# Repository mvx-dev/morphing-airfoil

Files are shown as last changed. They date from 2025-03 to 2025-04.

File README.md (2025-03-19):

# DESN1K Morphing Wing Main Repository
---
The main repository for uploading project files for the morphing wing project.

## Directories
---
Airfoils: any files relating to airfoil design. This include txt files, STL files, and Solidworks part files

Minutes: the minutes for every meeting

Embedded Systems: all files relating to embedded system design. This includes schematics, PCB files, etc

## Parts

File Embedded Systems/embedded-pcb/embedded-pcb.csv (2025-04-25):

Reference | Qty | Value | Footprint
A1 | 1 | Arduino_Nano_v2.x | Module:Arduino_Nano
C1,C2 | 2 | 220nF | Capacitor_THT:C_Disc_D3.8mm_W2.6mm_P2.50mm
C3,C4 | 2 | 10uF | Capacitor_THT:CP_Radial_D5.0mm_P2.50mm
D1,D2 | 2 | LED | LED_THT:LED_D5.0mm
J1 | 1 | Servos | Connector_PinSocket_2.54mm:PinSocket_1x06_P2.54mm_Vertical
J2 | 1 | Screw_Terminal_01x02 | TerminalBlock:TerminalBlock_bornier-2_P5.08mm
R1,R2,R3,R4 | 4 | 220 | Resistor_THT:R_Axial_DIN0207_L6.3mm_D2.5mm_P10.16mm_Horizontal
R5,R6,R7,R8 | 4 | 1k | Resistor_THT:R_Axial_DIN0207_L6.3mm_D2.5mm_P10.16mm_Horizontal
R9,R10 | 2 | 47 | Resistor_THT:R_Axial_DIN0207_L6.3mm_D2.5mm_P10.16mm_Horizontal
Rsen1,Rsen2 | 2 | 10k | Resistor_THT:R_Axial_DIN0207_L6.3mm_D2.5mm_P10.16mm_Horizontal
RV1,RV2 | 2 | 1k | Connector_Wire:SolderWire-0.1sqmm_1x03_P3.6mm_D0.4mm_OD1mm
SW1,SW2,SW3 | 3 | SW_SPDT | Connector_Wire:SolderWire-0.1sqmm_1x03_P3.6mm_D0.4mm_OD1mm
U1 | 1 | LM324 | Package_DIP:DIP-14_W7.62mm
U2 | 1 | LM7805_TO220 | Package_TO_SOT_THT:TO-220-3_Vertical
U3 | 1 | LM1117T-3.3 | Package_TO_SOT_THT:TO-220-3_Vertical

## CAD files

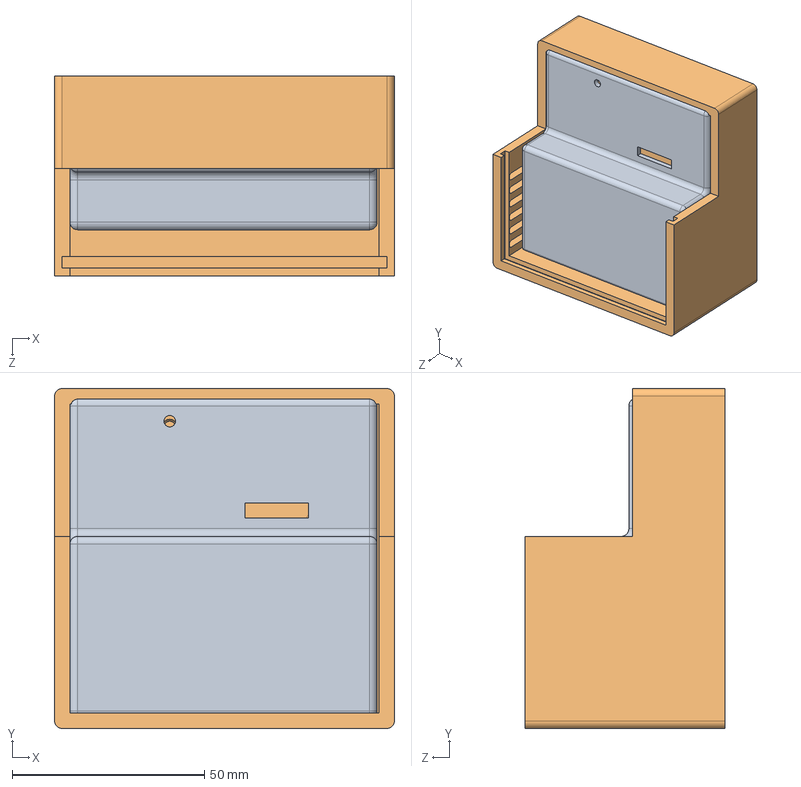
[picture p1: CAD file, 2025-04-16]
Embedded Systems/Housing/housing.SLDASM
88.5 x 88.5 x 52.0 mm
bottom-housing
cover

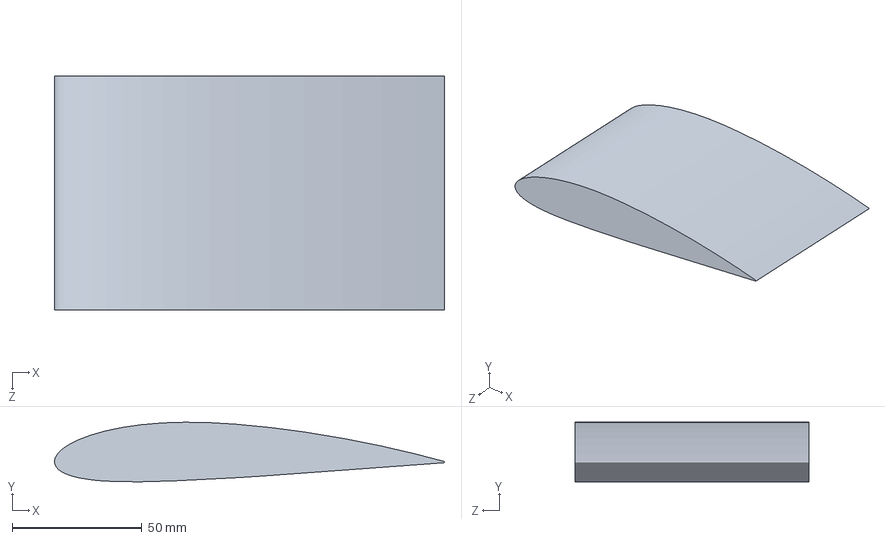
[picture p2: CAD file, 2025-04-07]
Airfoils/3415 airfoil base.SLDPRT
150.1 x 23.0 x 90.0 mm

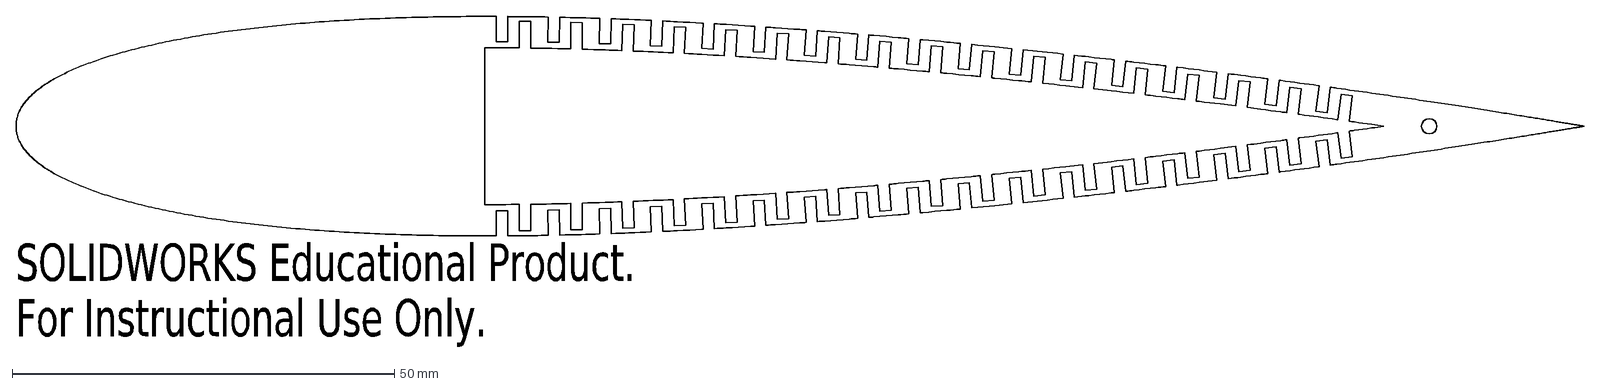
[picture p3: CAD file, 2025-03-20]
Mechanisms/Adam/0014v2.DXF
SOLIDWORKS Educational Product.
For Instructional Use Only.

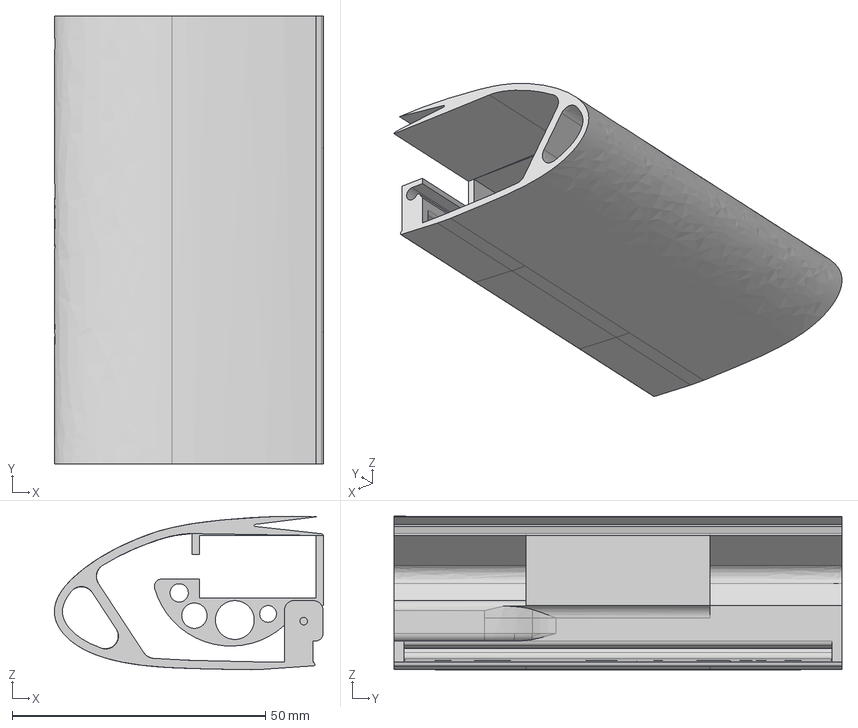
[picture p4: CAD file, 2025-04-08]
Mechanisms/CG V7 core.step
53.1 x 88.4 x 30.3 mm

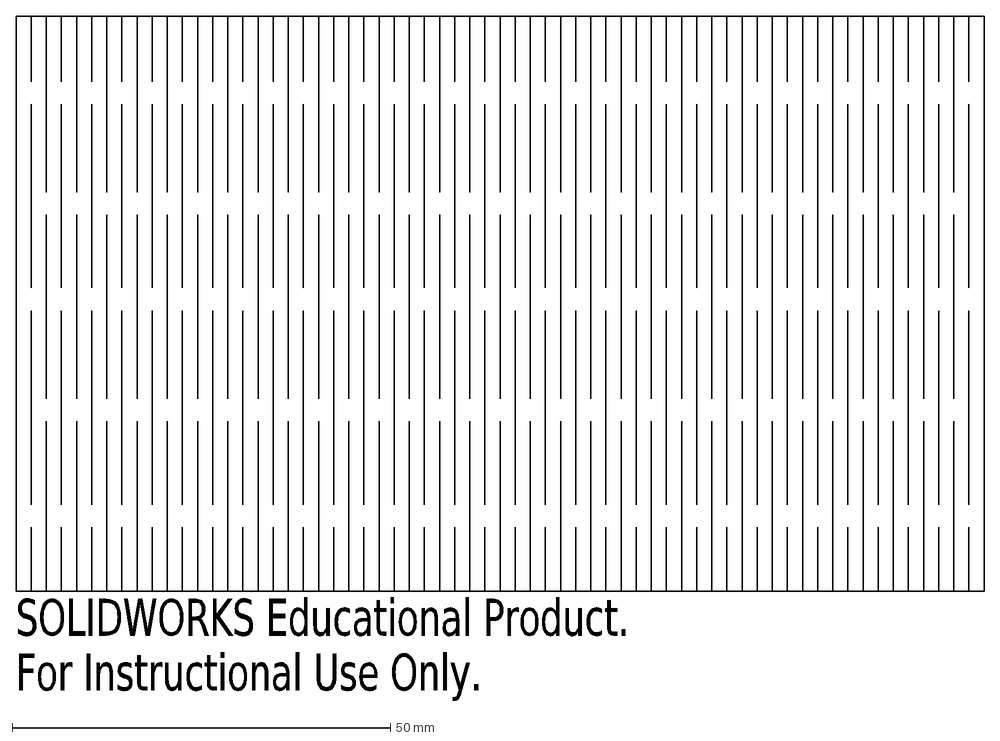
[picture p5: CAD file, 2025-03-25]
Mechanisms/Oskar/flexible-skin2.DXF
SOLIDWORKS Educational Product.
For Instructional Use Only.

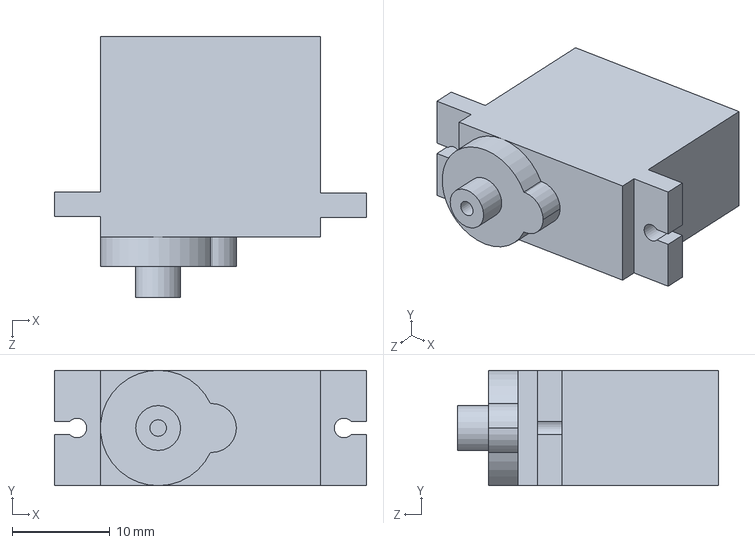
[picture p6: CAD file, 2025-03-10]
sg90.SLDPRT
31.9 x 11.8 x 26.7 mm

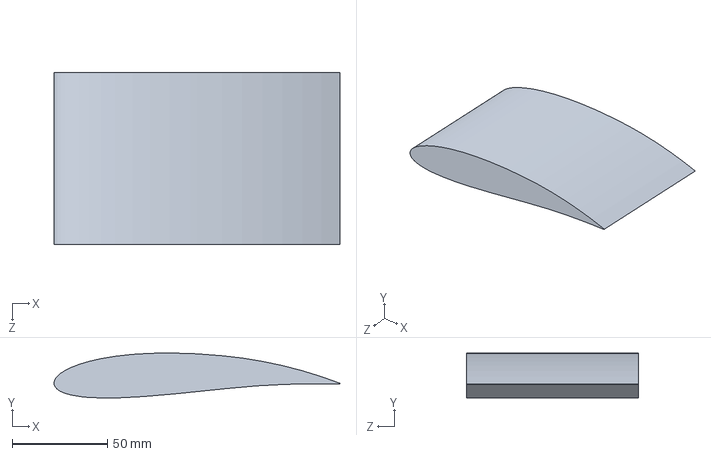
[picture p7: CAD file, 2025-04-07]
Airfoils/4615 airfoil base.SLDPRT
150.1 x 23.6 x 90.0 mm

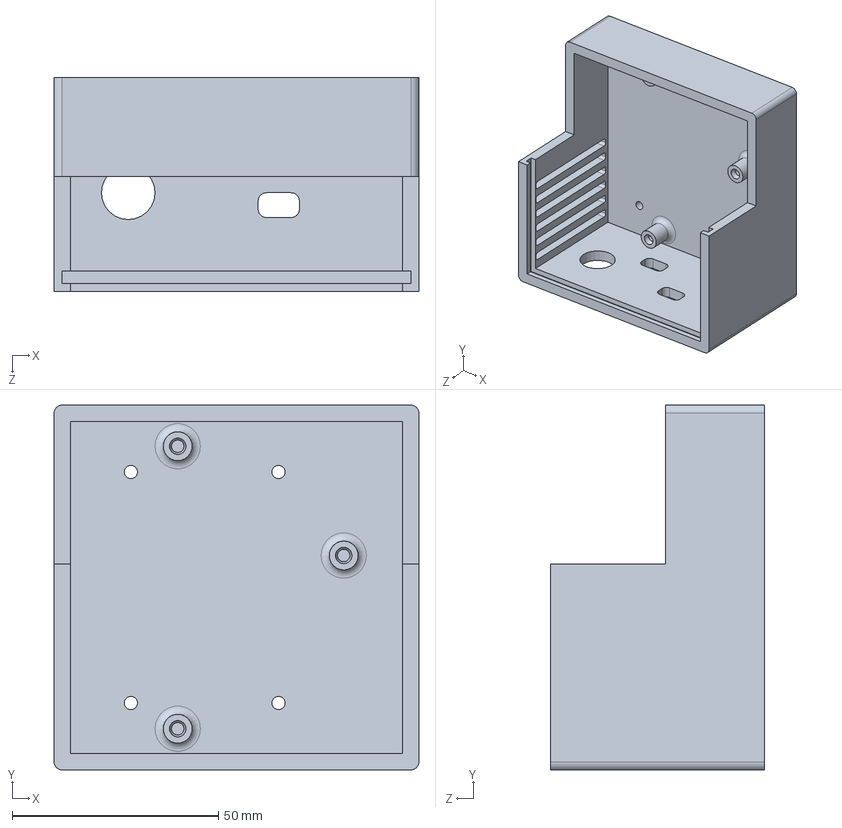
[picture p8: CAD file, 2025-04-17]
Embedded Systems/Housing/bottom-housing.SLDPRT
88.5 x 88.5 x 52.0 mm

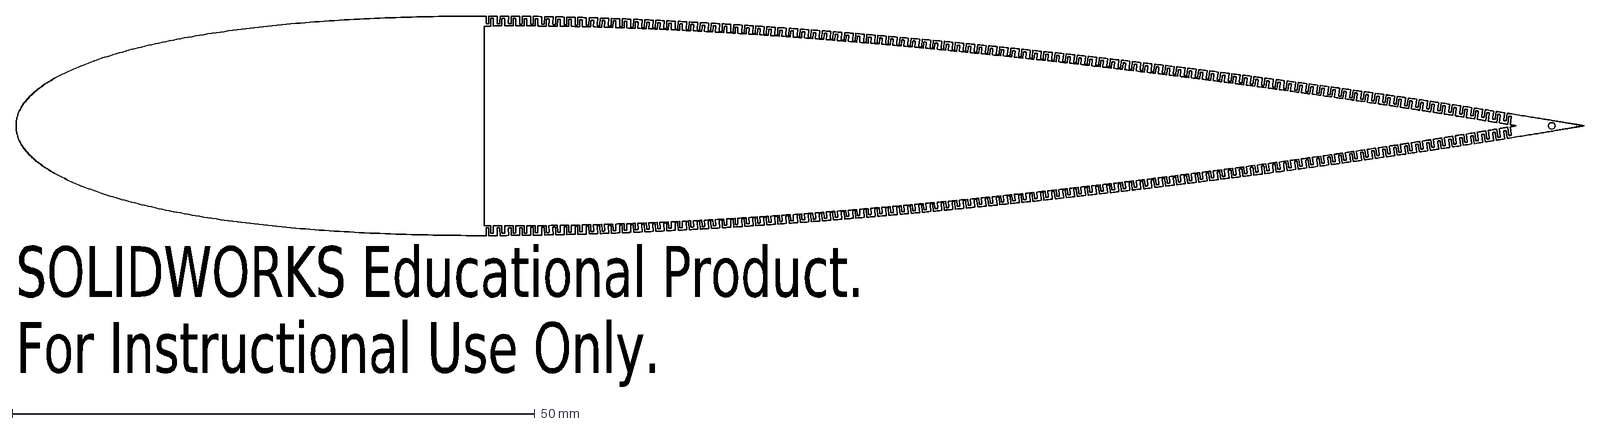
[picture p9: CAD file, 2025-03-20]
Mechanisms/Adam/0014v1.DXF
SOLIDWORKS Educational Product.
For Instructional Use Only.

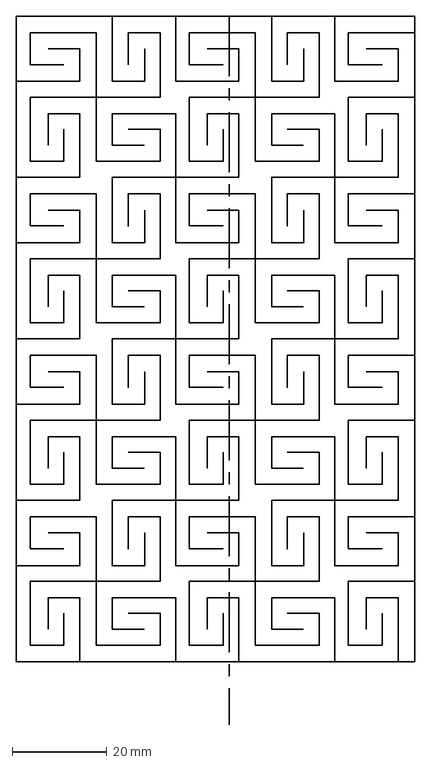
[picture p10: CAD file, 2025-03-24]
Mechanisms/Oskar/flexible-skin1.DXF
84.2 x 150.0 mm

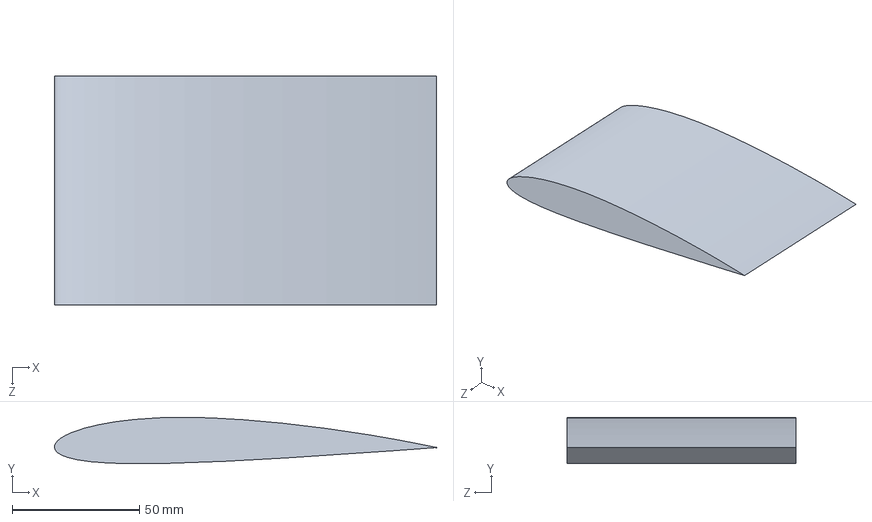
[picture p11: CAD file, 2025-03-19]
Airfoils/2412.SLDPRT
150.0 x 18.2 x 90.0 mm

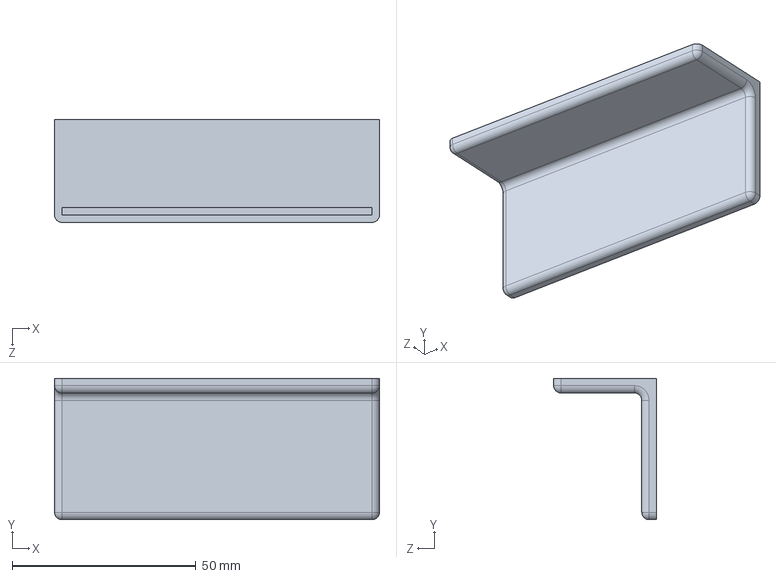
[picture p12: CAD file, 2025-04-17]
Embedded Systems/Housing/latch.SLDPRT
88.5 x 38.5 x 28.0 mm

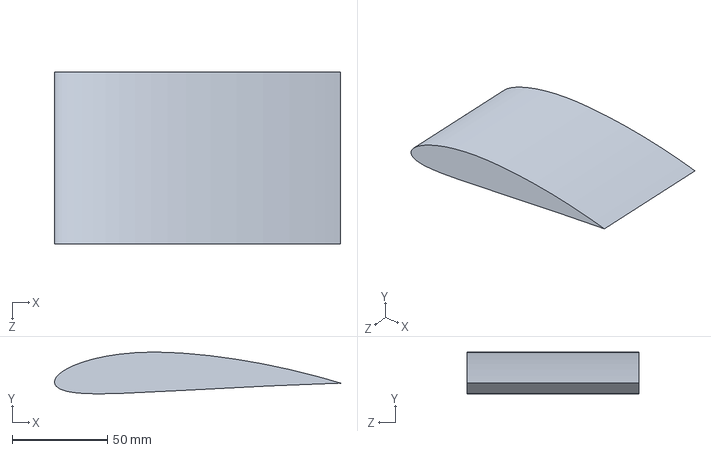
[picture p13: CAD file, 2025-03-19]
Airfoils/4414.SLDPRT
150.1 x 21.9 x 90.0 mm

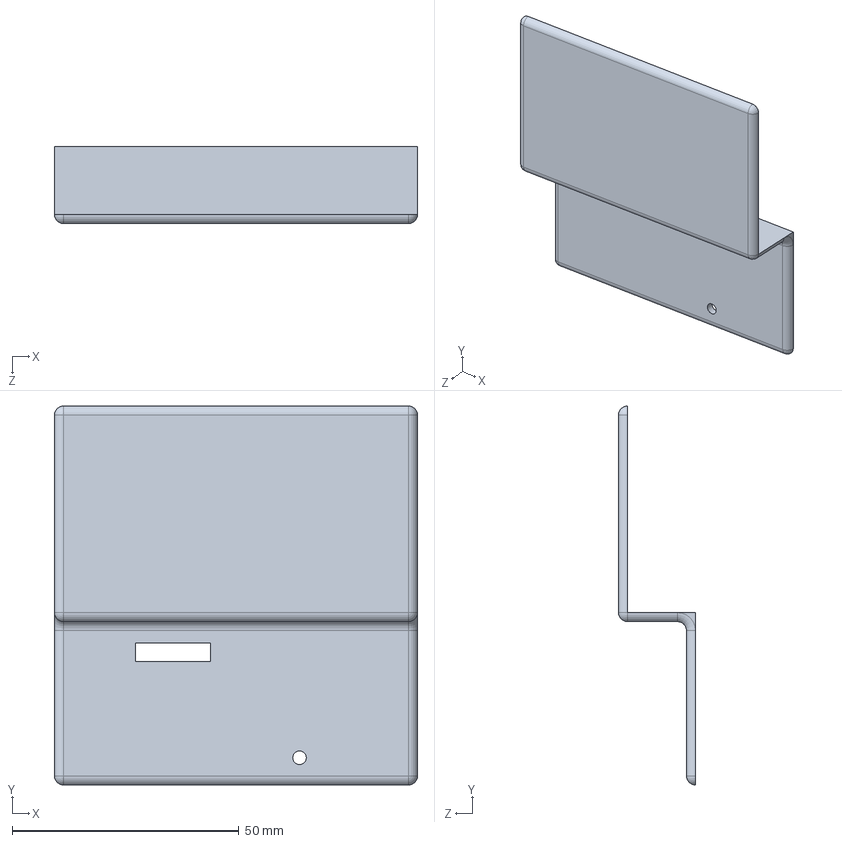
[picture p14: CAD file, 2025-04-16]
Embedded Systems/Housing/cover.SLDPRT
80.0 x 83.5 x 17.0 mm

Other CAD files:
Embedded Systems/Housing/lid.SLDPRT
Airfoils/2414.SLDPRT
Embedded Systems/Housing/baseplate.SLDPRT
Airfoils/2412.STL
Airfoils/2414.STL
Airfoils/4414.STL
Embedded Systems/Housing/lid.DXF

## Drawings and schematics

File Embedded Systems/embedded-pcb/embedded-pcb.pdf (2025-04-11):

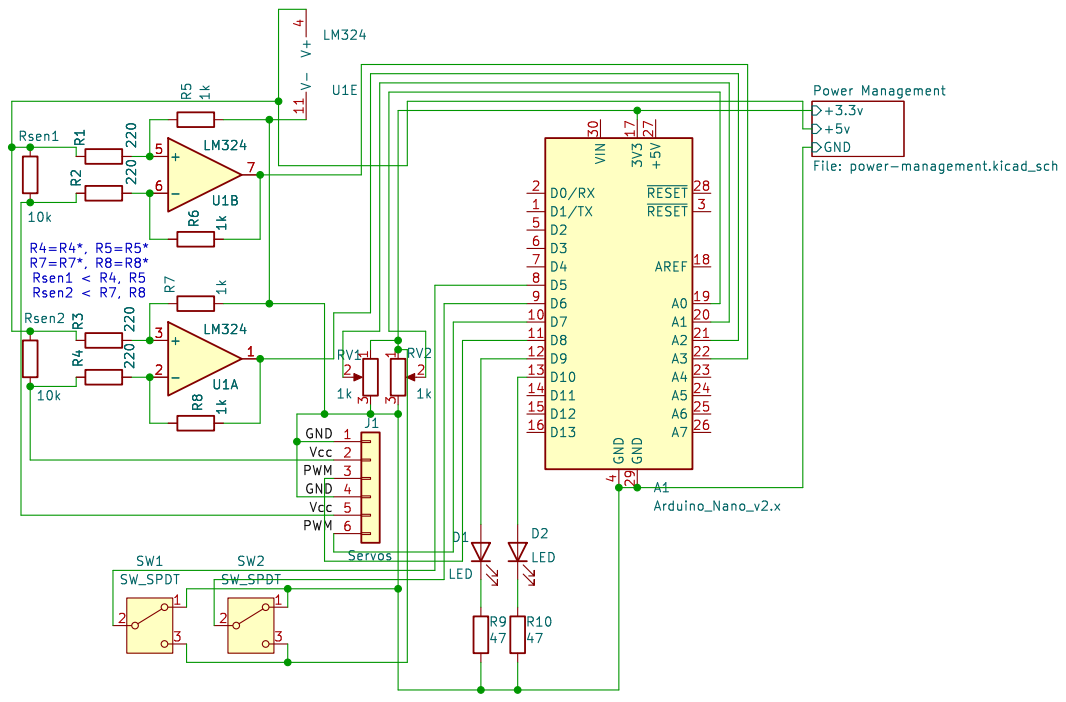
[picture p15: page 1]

Power Management File: power-management.kicad_sch D1

File: embedded-pcb.kicad_sch Sheet: / Email: o.meszaros@student.unsw.edu.au

Id: 1/2 Title: Morphing wing PCB

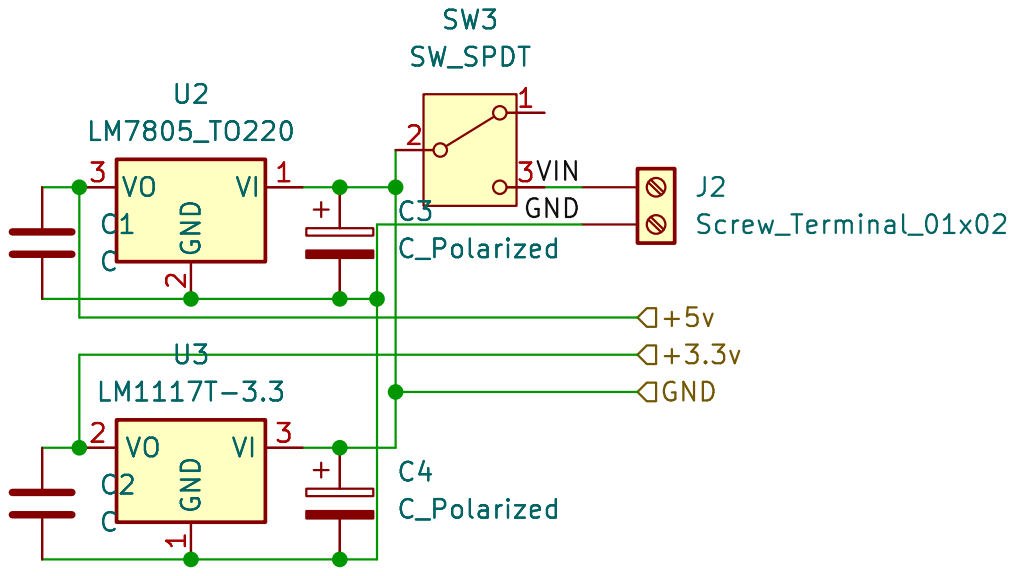
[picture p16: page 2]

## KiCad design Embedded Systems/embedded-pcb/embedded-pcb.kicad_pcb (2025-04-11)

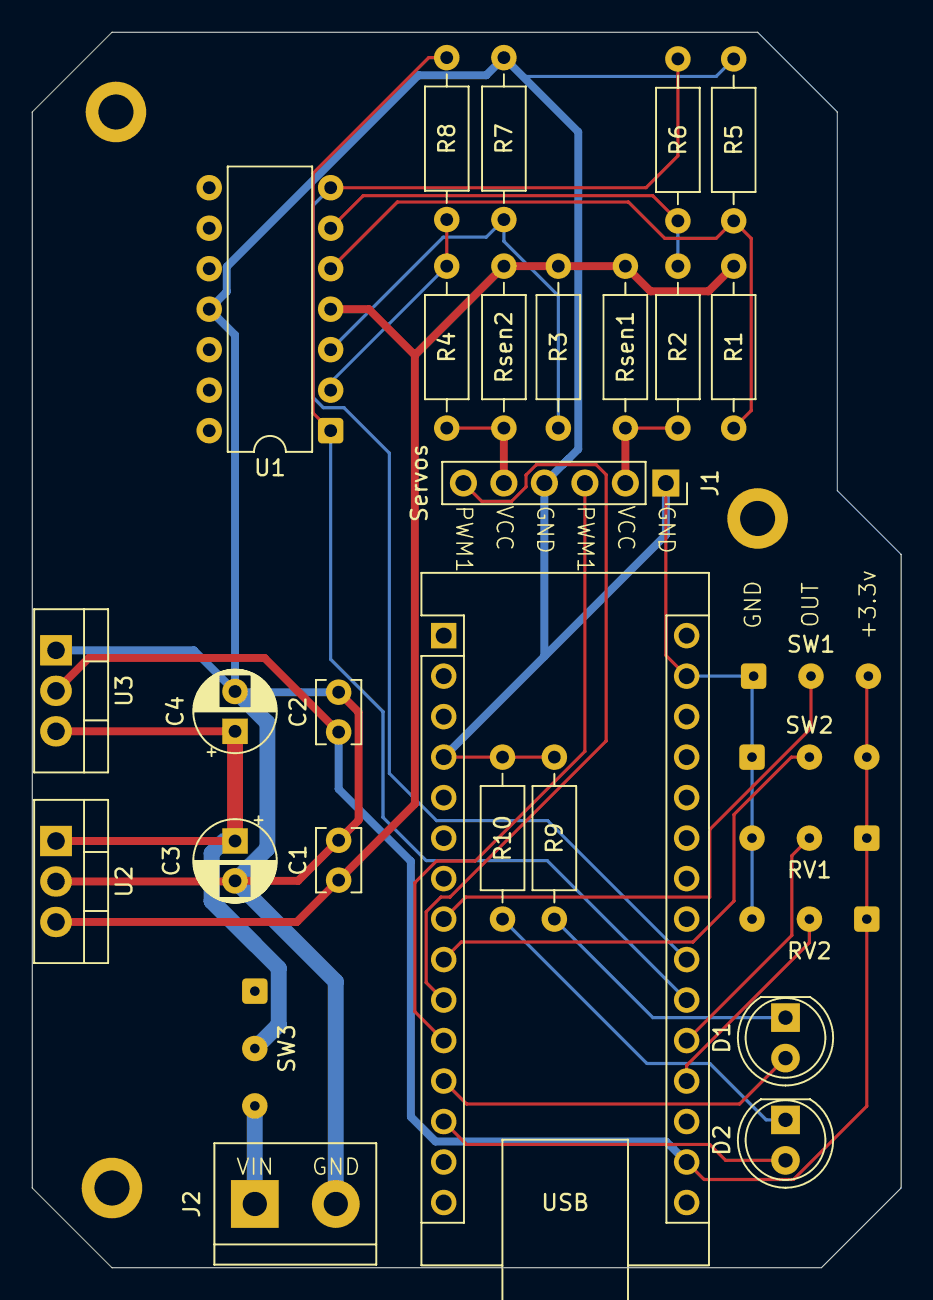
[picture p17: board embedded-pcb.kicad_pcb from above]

Board: 2 copper layers, 54.5 x 77.5 mm, 29 parts (0 on the bottom side), 20 nets.

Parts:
A1: Arduino_Nano_v2.x; Arduino_Nano
C1, C2: C; C_Disc_D3.8mm_W2.6mm_P2.50mm
C3, C4: C_Polarized; CP_Radial_D5.0mm_P2.50mm
D1, D2: LED; LED_D5.0mm
J1: Servos; PinSocket_1x06_P2.54mm_Vertical
J2: Screw_Terminal_01x02; TerminalBlock_bornier-2_P5.08mm
R1, R2, R3, R4: 220; R_Axial_DIN0207_L6.3mm_D2.5mm_P10.16mm_Horizontal
R5, R6, R7, R8: 1k; R_Axial_DIN0207_L6.3mm_D2.5mm_P10.16mm_Horizontal
R9, R10: 47; R_Axial_DIN0207_L6.3mm_D2.5mm_P10.16mm_Horizontal
RV1, RV2: 1k; SolderWire-0.1sqmm_1x03_P3.6mm_D0.4mm_OD1mm
Rsen1, Rsen2: 10k; R_Axial_DIN0207_L6.3mm_D2.5mm_P10.16mm_Horizontal
SW1, SW2, SW3: SW_SPDT; SolderWire-0.1sqmm_1x03_P3.6mm_D0.4mm_OD1mm
U1: LM324; DIP-14_W7.62mm
U2: LM7805_TO220; TO-220-3_Vertical
U3: LM1117T-3.3; TO-220-3_Vertical

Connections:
/GND: A1.4 (GND), A1.29 (GND), C1.2, C2.2, C3.1, C3.2, C4.1, C4.2, J1.1, J1.4, J2.2, R5.2, R7.2, R9.2, R10.2, RV1.3, RV2.3, SW1.1 (A), SW2.1 (A), SW3.2 (B), U1.11 (V-), U2.1 (VI), U2.2 (GND), U3.1 (GND), U3.3 (VI)
/PWM: A1.10 (D7), A1.11 (D8), J1.3, J1.6
/Power Management/+3.3v: A1.17 (3V3), C2.1, RV1.1, RV2.1, SW1.3 (C), SW2.3 (C), U3.2 (VO)
/Power Management/+5v: C1.1, R1.1, R3.1, Rsen1.1, Rsen2.1, U1.4 (V+), U2.3 (VO)
/Power Management/VIN: J2.1, SW3.3 (C)
/Vcc: J1.2, J1.5, R2.1, R4.1, Rsen1.2, Rsen2.2
unnamed: A1.19 (A0), RV2.2
unnamed: A1.20 (A1), RV1.2
unnamed: A1.21 (A2), R8.2, U1.1
unnamed: A1.22 (A3), R6.2, U1.7
unnamed: A1.8 (D5), SW1.2 (B)
unnamed: A1.9 (D6), SW2.2 (B)
unnamed: A1.12 (D9), D1.2 (A)
unnamed: A1.13 (D10), D2.2 (A)
unnamed: D1.1 (K), R9.1
unnamed: D2.1 (K), R10.1
unnamed: R3.2, R7.1, U1.3 (+)
unnamed: R4.2, R8.1, U1.2 (-)
unnamed: R1.2, R5.1, U1.5 (+)
unnamed: R2.2, R6.1, U1.6 (-)

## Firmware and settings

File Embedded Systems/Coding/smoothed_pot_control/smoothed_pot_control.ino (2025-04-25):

/*
  smoothed_pot_control v1.0

  Controls two servos by reading the voltage across two potentiometers, and
  optionally smooth the outputs by calculating a sliding average.

  created 03 Apr 2025
  by Oskar Meszaros
  zID z5636164
  email o.meszaros@student.unsw.edu.au
*/
#include <Servo.h>

/* Define I/O pins */
const int POT1 = A0;
const int POT2 = A1;
const int LEDPIN1 = 2; // LED1 in use
const int LEDPIN2 = 3; // LED2 in use
const int SWITCH2 = 4;
const int SWITCH1 = 5;
const int SERVO1 = 9;
const int SERVO2 = 7;

/* Define servos*/
Servo servo1;
Servo servo2;

/* Define program variables*/
int servo1_pos = 0;
int servo2_pos = 0;
int pot1_value = 0;
int pot2_value = 0;
int pot1_old = 0;
int pot2_old = 0;
int switch1_value = LOW; // LOW = Smoothing off, HIGH = Smoothing on
int switch2_value = LOW;

int threshold = 4;
bool moving = false;

const int smoothingSteps = 48;
int pot1_readings[smoothingSteps] = {0};
int pot2_readings[smoothingSteps] = {0};

int pot_to_servo(int value) {
  /* Translate potentiometer value to servo position */
  return (value/1023.0) * 180;
}

int smooth_value(int value, int readings[]) {
  /* Update the reading buffer and return average */
  int total = 0;
  
  for (int i = 0; i < smoothingSteps-1; i++) {
    readings[i] = readings[i+1];
    total += readings[i];
  }

  readings[smoothingSteps-1] = value;
  total += value;
  
  return (int)(total/smoothingSteps);
}

void calibrate(int cycles, int gap, int pot_pin, int readings[]) {
  /*
  Propogates the buffer with values to prevent the servo moving prior to having the correction position.
  Fills buffer cycles times.
  */
  for (int cycle = 0; cycle < cycles; cycle++){
    for (int i = 0; i < smoothingSteps; i++) {
      int pot_value = analogRead(pot_pin);
      smooth_value(pot_value, readings);
      delay(gap);
    }
  }
}

void setup() {
  /* Configure pins*/
  pinMode(LEDPIN1, OUTPUT);
  pinMode(LEDPIN2, OUTPUT);
  pinMode(SWITCH1, INPUT);
  pinMode(SWITCH2, INPUT);

  /* Attach Servos */
  servo1.attach(SERVO1);
  servo2.attach(SERVO2);

  /* Calibrate potentiometer smoothing */
  digitalWrite(LEDPIN1, HIGH);
  calibrate(8, 10, POT1, pot1_readings);
  calibrate(8, 10, POT2, pot2_readings);
  digitalWrite(LEDPIN1, LOW);
  delay(100);
  digitalWrite(LEDPIN1, HIGH);
  delay(100);
  digitalWrite(LEDPIN1, LOW);

  /* Begin Serial */
  Serial.begin(9600);
}

void loop() {
  /* Read all inputs */
  pot1_old = pot1_value;
  pot2_old = pot2_value;
  pot1_value = analogRead(POT1);
  pot2_value = analogRead(POT2);

  switch1_value = digitalRead(SWITCH1);
  switch2_value = digitalRead(SWITCH2);

  /* Smooth potentiometer input. Still add to buffer if not. */
  if (switch1_value == HIGH) {
    pot1_value = smooth_value(pot1_value, pot1_readings);
  } else {
    smooth_value(pot1_value, pot1_readings);
  }

  if (switch2_value == HIGH) {
    pot2_value = smooth_value(pot2_value, pot2_readings);
  } else {
    smooth_value(pot2_value, pot2_readings);
  }

  /* Indicator light*/
  int delta1 = pot1_old - pot1_value;
  int delta2 = pot2_old - pot2_value;

  if ((delta1 < -threshold) or (delta1 > threshold)) {
    moving = true;
  }
  if ((delta2 < -threshold) or (delta2 > threshold)) {
    moving = true;
  }

  if (moving) {
    moving = false;
    digitalWrite(LEDPIN1, HIGH);
    digitalWrite(LEDPIN2, LOW);
  } else {
    digitalWrite(LEDPIN1, LOW);
    digitalWrite(LEDPIN2, HIGH);
  }

  /* Update servos */
  servo1_pos = pot_to_servo(pot1_value);
  servo2_pos = pot_to_servo(pot2_value);

  servo1.write(servo1_pos);
  servo2.write(servo2_pos);

  delay(10);
}

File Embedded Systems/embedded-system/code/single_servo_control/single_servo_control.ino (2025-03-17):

#include <Servo.h>


Servo servo;  // create servo object to control a servo

// Define pins
const int POT_IN = A0;
// const int SERVO_IN = A1;
const int SERVO_OUT = 10;

// Program variables
int servo_pos = 0;
int pot_value = 0;
int servo_value = 0;

float potToServo(int pot) {
  float ratio = pot / 1023.0;
  return ratio * 180.0;
}

void setup() {
  servo.attach(SERVO_OUT);  // attaches the servo on pin 9 to the servo object
  servo.write(0);  // Home it to 0
  delay(50);

  // Configure serial
  Serial.begin(9600);
}

void loop() {
  pot_value = analogRead(POT_IN);
  servo_pos = potToServo(pot_value);
  // servo_value = analogRead(SERVO_IN);
  Serial.print(pot_value);
  Serial.print("\t");
  // Serial.print(servo_value);
  // Serial.print("\t");
  Serial.println(servo_pos);

  servo.write(servo_pos);

  delay(10);
}

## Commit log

2025-03-10 feat: SG90 solidworks part
    3D model of the SG90 servo motor for use in the morphing wing
    [sg90.SLDPRT]
2025-03-14 feat: embedded system project files
    [embedded-system.kicad_pcb, embedded-system.kicad_sch]
2025-03-15 feat: added schematic for embedded systems
    Designed a basic PCB for the embedded system
    [embedded-pcb.kicad_pcb, embedded-pcb.kicad_sch, embedded-system.kicad_sch]
2025-03-17 feat: small update to schematic
    [embedded-pcb.kicad_sch]
2025-03-17 feat: single servo control
    Code for controlling a single servo using a trim pot
2025-03-18 feat: optimised tracks
    [embedded-pcb.kicad_pcb]
2025-03-19 update: latest backup for schematic
2025-03-19 feat: airfoil models
    Created 3D models for NACA 2412, NACA 2414, NACA 4414
    [2412.SLDPRT, 2412.STL, 2414.SLDPRT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]
2025-03-19 refactor: embedded-systems
    Rearranged the file structure of the embedded systems files
    [embedded-pcb.kicad_pcb, embedded-pcb.kicad_sch, embedded-system.kicad_pcb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]
2025-03-20 feat: uploaded compliant mechanism
    Added DXF file for the first revision for a compliant mechanism.
    [0014v1.DXF]
2025-03-20 refactor: rearranged mechanism files
    [0014v1.DXF]
2025-03-20 feat: Airfoil compliant mechanism revision 2
    [0014v2.DXF]
2025-03-22 feat: updated schematic
    [embedded-pcb.kicad_pcb, embedded-pcb.kicad_sch, embedded-system.kicad_sch]
2025-03-24 feat: uploaded first flexible skin design
    [flexible1.DXF]
2025-03-25 feat: updated schematic for 3.3v
    [embedded-pcb.kicad_sch]
2025-03-25 feat: uploaded flexible skin designs
    [flexible-skin1.DXF, flexible-skin2.DXF]
2025-03-27 feat: updated schematic PDF
2025-04-03 feat: added smoothing
    Added the ability to smooth the output of the potentiometers for servo control.
2025-04-03 feat: cleaned for release version
    Cleaned up the smoothing code, and finished the calibration function. This is v1.0 of the servo control code.
2025-04-07 Add files via upload
    3415, 4615 for wind tunnel testing
    Only the base shapes
    [3415 airfoil base.SLDPRT, 4615 airfoil base.SLDPRT]
2025-04-10 feat: added power management
    Added a basic circuit for power management. Supports 3.3v @ 0.8A and 5v @ 1.5A simultaneously.
    [power-module.kicad_sch, untitled.kicad_sch]
2025-04-10 feat: v2 of PCB design
    [embedded-pcb.kicad_pcb, embedded-pcb.kicad_sch]
2025-04-11 feat: updated power management
    [embedded-pcb.kicad_sch, power-management.kicad_sch]
2025-04-11 feat: finalised PCB
    Finalised the electrical design and PCB, including adding a power switch, silksreening, and mounting holes.
    [embedded-pcb.kicad_pcb, power-management.kicad_sch]
2025-04-11 feat: started housing design
    [baseplate.SLDPRT]
2025-04-11 feat: updated ES
    Basic schematic updates, prior versions uploaded
    [embedded-pcb.kicad_pcb, power-management.kicad_sch]
2025-04-16 feat: generated BOM
    [embedded-pcb.csv, power-management.kicad_sch]
2025-04-16 feat: first housing iteration
    [bottom-housing.SLDPRT, cover.SLDPRT, housing.SLDASM]
2025-04-17 feat: designed lid
    [bottom-housing.SLDPRT, latch.SLDPRT, lid.DXF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]
2025-04-25 feat: updated pcb
2025-04-25 feat: generated parts list
    [embedded-pcb.csv]
